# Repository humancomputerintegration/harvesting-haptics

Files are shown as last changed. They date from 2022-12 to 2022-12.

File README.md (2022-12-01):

# source files for "Prolonging VR haptic experiences by harvesting kinetic energy from the user"

For implementation details, please refer to our paper: http://lab.plopes.org/#harvesting-haptics

- schematics: circuits used on PCB.
- code: containing Arduino code for NRF controller, Python code for connecting to NRF controller, and Processing code for intermediate program communicating to any Unity application (VR).
- waterjet: mounting plates and the big gear were cut using a waterjet machine, with 3mm Aluminum. Parts are assembled using M2 and M3 screws, mounted on elbow brace (MOSCARE).
- 3D printing: three gears are 3D printed with PLA.

## additional materials

- NRF52840 Dongle
- harvester (ZSFD-F1HD)
- electro-permanent magnet: Alnico Grade 5 soft magnet + 28 AWG coil
- neodymium magnets
- 8mm bearing
- 5mm ABS shafts

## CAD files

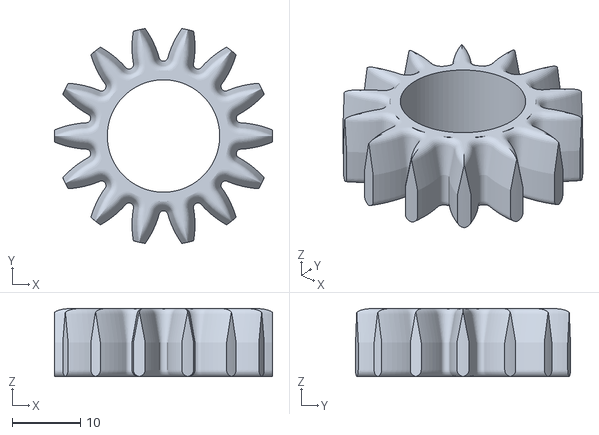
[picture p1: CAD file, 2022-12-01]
3dprinting/gear_clutch.stl
32.0 x 31.5 x 10.0

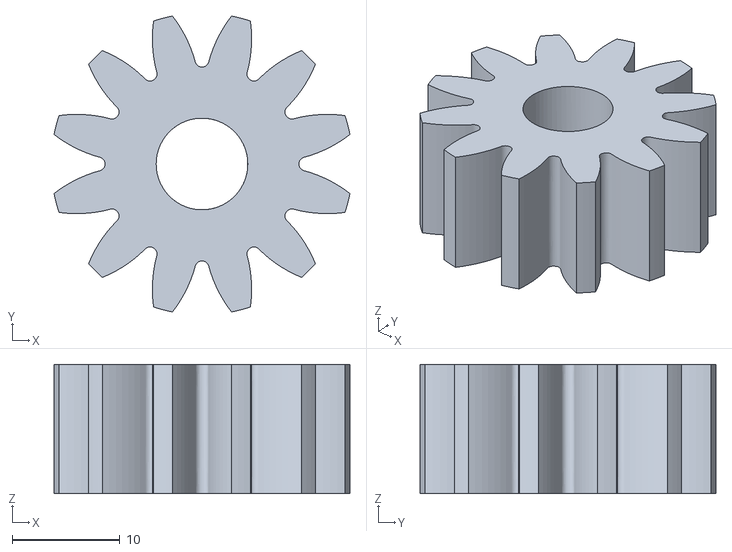
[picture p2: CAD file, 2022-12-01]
3dprinting/gear_middle.stl
27.5 x 27.5 x 12.0

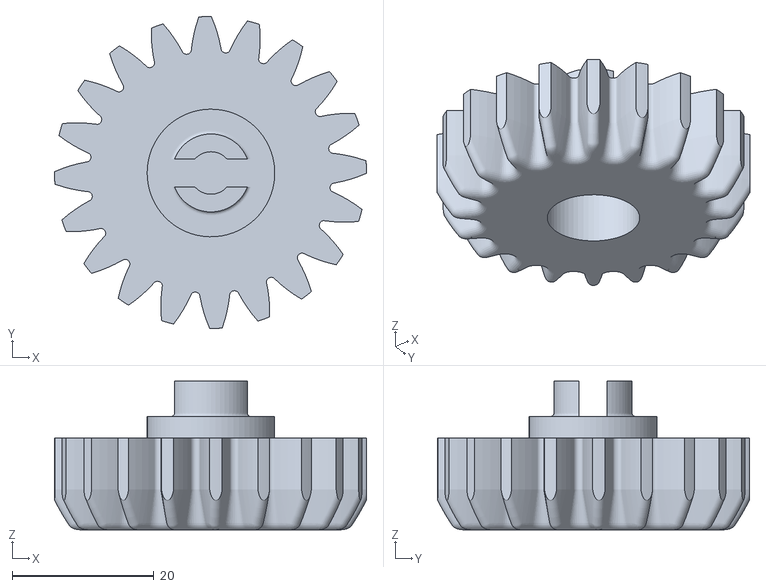
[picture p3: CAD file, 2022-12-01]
3dprinting/gear_harvester.stl
44.0 x 44.0 x 21.0

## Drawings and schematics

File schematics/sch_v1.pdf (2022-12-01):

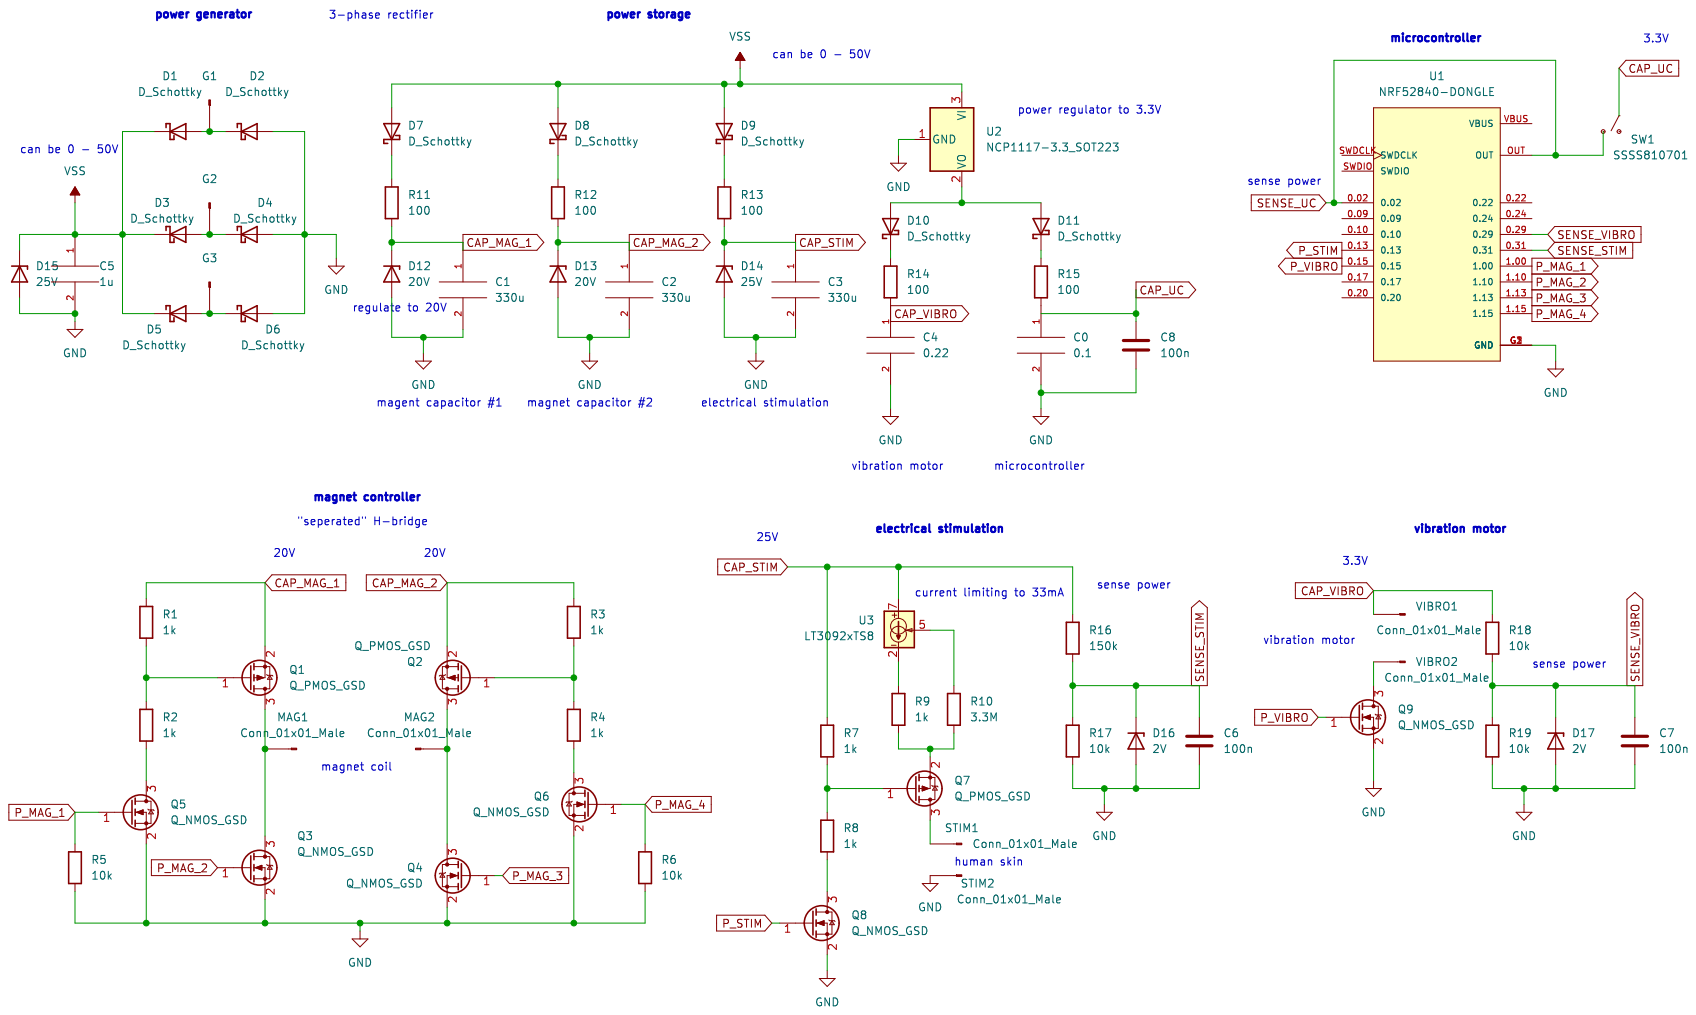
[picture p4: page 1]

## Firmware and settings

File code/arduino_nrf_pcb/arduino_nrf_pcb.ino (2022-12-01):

#include <bluefruit.h>
#include <Adafruit_LittleFS.h>
#include <InternalFileSystem.h>

// BLE Service
BLEUart bleuart; // uart over ble

#define LED_PIN 8
#define SW1_PIN 38

#define BATT_SENSE_PIN 2
#define VIBRO_SENSE_PIN 29
#define EMS_SENSE_PIN 31
#define EPM_1_PIN 32
#define EPM_2_PIN 42
#define EPM_3_PIN 45
#define EPM_4_PIN 47
#define VIBRO_PIN 15
#define EMS_PIN 13

int batt_sense = 0;
int vibro_sense = 0;
int ems_sense = 0;
unsigned long last_time, current_time;


void setup() {
  pinMode(LED_PIN, OUTPUT);
  pinMode(EPM_1_PIN, OUTPUT);
  pinMode(EPM_2_PIN, OUTPUT);
  pinMode(EPM_3_PIN, OUTPUT);
  pinMode(EPM_4_PIN, OUTPUT);
  pinMode(VIBRO_PIN, OUTPUT);
  pinMode(EMS_PIN, OUTPUT);
  pinMode(BATT_SENSE_PIN, INPUT);
  pinMode(VIBRO_SENSE_PIN, INPUT);
  pinMode(EMS_SENSE_PIN, INPUT);
  pinMode(SW1_PIN, INPUT_PULLUP);
  
  digitalWrite(EPM_1_PIN, LOW);
  digitalWrite(EPM_2_PIN, LOW);
  digitalWrite(EPM_3_PIN, LOW);
  digitalWrite(EPM_4_PIN, LOW);
  digitalWrite(VIBRO_PIN, LOW);
  digitalWrite(EMS_PIN, LOW);

  start_ble();
}

void loop() {
  if ( bleuart.available() )
  {
    uint8_t ch;
    ch = (uint8_t) bleuart.read();
    int cmd = ch - '0';

    // turn off everything
    if (cmd == 0) {
      digitalWrite(EPM_1_PIN, LOW);
      digitalWrite(EPM_2_PIN, LOW);
      digitalWrite(EPM_3_PIN, LOW);
      digitalWrite(EPM_4_PIN, LOW);
      // report vibro
      ems_sense = analogRead(EMS_SENSE_PIN);
      bleuart.print(ems_sense);
      bleuart.println();
    }

    // EPM out (unclutch)
    if (cmd == 1) {
      digitalWrite(EPM_1_PIN, HIGH);
      digitalWrite(EPM_3_PIN, HIGH);
      digitalWrite(EPM_2_PIN, LOW);
      digitalWrite(EPM_4_PIN, LOW);
    }
    // EPM in (clutch)
    if (cmd == 2) {
      digitalWrite(EPM_1_PIN, LOW);
      digitalWrite(EPM_3_PIN, LOW);
      digitalWrite(EPM_2_PIN, HIGH);
      digitalWrite(EPM_4_PIN, HIGH);
    }
    // EPM out (unclutch) with timing
    if (cmd == 3) {
      digitalWrite(EPM_1_PIN, HIGH);
      digitalWrite(EPM_3_PIN, HIGH);
      digitalWrite(EPM_2_PIN, LOW);
      digitalWrite(EPM_4_PIN, LOW);
      delay(500);
      digitalWrite(EPM_1_PIN, LOW);
      digitalWrite(EPM_3_PIN, LOW);
      digitalWrite(EPM_2_PIN, LOW);
      digitalWrite(EPM_4_PIN, LOW);
    }
    // EPM in (clutch) with timing
    if (cmd == 4) {
      digitalWrite(EPM_1_PIN, LOW);
      digitalWrite(EPM_3_PIN, LOW);
      digitalWrite(EPM_2_PIN, HIGH);
      digitalWrite(EPM_4_PIN, HIGH);
      delay(500);
      digitalWrite(EPM_1_PIN, LOW);
      digitalWrite(EPM_3_PIN, LOW);
      digitalWrite(EPM_2_PIN, LOW);
      digitalWrite(EPM_4_PIN, LOW);
    }

    // vibration motor short vibration
    if (cmd == 5) {
      tone(VIBRO_PIN, 170);
      delay(300);
      noTone(VIBRO_PIN);
    }
    // long vibration
    if (cmd == 6) {
      tone(VIBRO_PIN, 170);
      delay(900);
      noTone(VIBRO_PIN);
    }

    // EMS
    if (cmd == 7) {
      int repeat = 20;
      for (int i = 0; i<repeat; i++) {
        digitalWrite(EMS_PIN, HIGH);
        delayMicroseconds(200);
        digitalWrite(EMS_PIN, LOW);
        delay(20); //ms
      }
    }

    // long ems
    if (cmd == 8) {
      int repeat = 40;
      for (int i = 0; i<repeat; i++) {
        digitalWrite(EMS_PIN, HIGH);
        delayMicroseconds(200);
        digitalWrite(EMS_PIN, LOW);
        delay(20); //ms
      }
    }
    
    if (cmd == 9) {
      // report battery
      batt_sense = analogRead(BATT_SENSE_PIN);
      bleuart.print(batt_sense);
      bleuart.println();
//      // report vibro
//      vibro_sense = analogRead(VIBRO_SENSE_PIN);
//      bleuart.print(vibro_sense);
//      bleuart.println();
    }
  }

  delay(100); // important to save power
}

void start_ble()
{
  Bluefruit.autoConnLed(false);
  Bluefruit.begin();
  Bluefruit.setTxPower(-16);    // Check bluefruit.h for supported values
  Bluefruit.setName("Harvest");
  //Bluefruit.setName(getMcuUniqueID()); // useful testing with multiple central connections
  Bluefruit.Periph.setConnectCallback(connect_callback);
  Bluefruit.Periph.setDisconnectCallback(disconnect_callback);
  // Configure and Start BLE Uart Service
  bleuart.begin();
  // Set up and start advertising
  startAdv();
}

void startAdv(void)
{
  // Advertising packet
  Bluefruit.Advertising.addFlags(BLE_GAP_ADV_FLAGS_LE_ONLY_GENERAL_DISC_MODE);
  // Bluefruit.Advertising.addTxPower();

  // Include bleuart 128-bit uuid
  Bluefruit.Advertising.addService(bleuart);

  // Secondary Scan Response packet (optional)
  // Since there is no room for 'Name' in Advertising packet
  Bluefruit.ScanResponse.addName();

  /* Start Advertising
     - Enable auto advertising if disconnected
     - Interval:  fast mode = 20 ms, slow mode = 152.5 ms
     - Timeout for fast mode is 30 seconds
     - Start(timeout) with timeout = 0 will advertise forever (until connected)

     For recommended advertising interval
     https://developer.apple.com/library/content/qa/qa1931/_index.html
  */
  Bluefruit.Advertising.restartOnDisconnect(true);
  Bluefruit.Advertising.setInterval(244, 244);    // in unit of 0.625 ms
  Bluefruit.Advertising.setFastTimeout(0);      // number of seconds in fast mode
  Bluefruit.Advertising.start(0);                // 0 = Don't stop advertising after n seconds
}

// callback invoked when central connects
void connect_callback(uint16_t conn_handle)
{
  // Get the reference to current connection
  BLEConnection* connection = Bluefruit.Connection(conn_handle);

  char central_name[32] = { 0 };
  connection->getPeerName(central_name, sizeof(central_name));

  //  Serial.print("Connected to ");
  //  Serial.println(central_name);
}

/**
   Callback invoked when a connection is dropped
   @param conn_handle connection where this event happens
   @param reason is a BLE_HCI_STATUS_CODE which can be found in ble_hci.h
*/
void disconnect_callback(uint16_t conn_handle, uint8_t reason)
{
  (void) conn_handle;
  (void) reason;

  //  Serial.println();
  //  Serial.print("Disconnected, reason = 0x"); Serial.println(reason, HEX);
}

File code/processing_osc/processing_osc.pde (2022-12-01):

import netP5.*;
import oscP5.*;


OscP5 oscP5;

/* a NetAddress contains the ip address and port number of a remote location in the network. */
NetAddress oscPythonBroadcastLocation; 
NetAddress oscUnityBroadcastLocation; 

// OSC sercer address and port
int port_in = 5005;
//String ip_python = "169.254.0.1";
String ip_python = "10.150.30.79";
//String ip_python = "192.168.0.102";
int port_out_python = 5006;
//String ip_unity = "169.254.207.164";
String ip_unity = "10.150.26.114";
//String ip_unity = "192.168.0.1";
int port_out_unity = 5007;

int power = 0;

int timerStart = 0;
int timerInterval = 1000;

int movingAvgSize = 20;
int[] movingArray = new int[20];
int movingArrayIdx = 0;

int emergencyLowPower = 500;
int stableThreshold = 650;
int maxVibroTimes = 10;
int currentVibroTimes = 0;

boolean connected = false;
boolean stable = false;
boolean emergencyStep = false;

PrintWriter log;

void setup() {
  size(400,400);
  frameRate(25);
  
  oscP5 = new OscP5(this, port_in);
  oscPythonBroadcastLocation = new NetAddress(ip_python, port_out_python);
  oscUnityBroadcastLocation = new NetAddress(ip_unity, port_out_unity);
  
  timerStart = millis();
  
  for (int i = 0; i<movingAvgSize; i+=1) {
    movingArray[i] = 0;
  }
  
  log = createWriter("log-"+year()+"-"+month()+"-"+day()+"-"+hour()+"-"+minute()+"-"+second()+".csv"); 
  log.println("hour,minute,second,game_state,device_state");
}


void draw() {
  background(0);
  
  textSize(18);
  fill(255, 255, 255);
  text("python " + ip_python, 10, 30);
  text("unity " + ip_unity, 10, 50);
  
  textSize(28);
  
  if (connected && stable && emergencyStep) {
    text("emergency " + str(power), 10, 120);
  } else if (connected && stable) {
    text("stable " + str(power), 10, 120);
  } else if (connected) {
    text("connected " + str(power), 10, 120);
  } else {
    text("dead", 10, 120);
  }
  
  text("BLE: 0 (off), 1 (in), 2 (out)", 10, 180);
  text("     3 (in timer), 4 (out timer)", 10, 210);
  text("     5 (vib short) 6 (vib long) ", 10, 240);
  text("     7 (ems), 9 (connect)", 10, 270);
  text("VR:  s (stable) d (dying)", 10, 300);
  text("LOG: g (start) e (end)", 10, 330);
  
  // if connected, check power at times
  if (millis() - timerStart > timerInterval) {
    if (connected) {
      sendMessageToBLE(9);
    }
    timerStart = millis();
  }
  
  // estimatation of vibro power
  //if (currentVibroTimes >= maxVibroTimes) {
  //  println("send OSC to Unity: dying because run out of vibro power");
  //  log.println(timestamp()+","+"vibro_cemergency");
  //  log.flush();
  //}
  

  
}

void keyPressed() {
  OscMessage m;
  if (key == CODED) {
    if (keyCode == UP) {
      
    } else if (keyCode == DOWN) {
      
    } else if (keyCode == LEFT) {
      
    } else if (keyCode == RIGHT) {
     
    }
  } else {
    switch(key) {
      case('1'):
        sendMessageToBLE(1);
        log.println(timestamp()+","+"manual_clutch");
        log.flush();
        break;
      case('2'):
        sendMessageToBLE(2);
        log.println(timestamp()+","+"manual_unclutch");
        log.flush();
        break;
      case('3'):
        sendMessageToBLE(3);
        log.println(timestamp()+","+"manual_clutch_timeout");
        log.flush();
        break;
      case('4'):
        sendMessageToBLE(4);
        log.println(timestamp()+","+"manual_unclutch_timeout");
        log.flush();
        break;
      case('5'):
        sendMessageToBLE(5);
        log.println(timestamp()+","+"manual_vibro");
        log.flush();
        break;
      case('6'):
        sendMessageToBLE(6);
        log.println(timestamp()+","+"manual_vibro_long");
        log.flush();
        break;
      case('7'):
        sendMessageToBLE(7);
        log.println(timestamp()+","+"manual_ems");
        log.flush();
        break;
      case('8'):
        sendMessageToBLE(8);
        break;
      case('9'):
        sendMessageToBLE(9);
        break;
      case('0'):
        sendMessageToBLE(0);
        break;
      case(' '):
        sendMessageToBLE(3);
        log.println(timestamp()+","+"manual_unclutch_timeout");
        log.flush();
        break;
      case('a'):
        sendMessageSOSToBLE();
        break;
      case('b'):
        sendMessageVibrosToBLE();
        break;
      case('g'):
        println("log > game start");
        log.println(timestamp()+"game_start");
        log.flush();
        break;
      case('e'):
        println("log > game end");
        log.println(timestamp()+"game_end");
        log.flush();
        break;
      case('s'):
        sendMessageToUnity(1);
        println("send OSC to Unity: stable");
        log.println(timestamp()+","+"manual_stable");
        log.flush();
        break;
      case('d'):
        sendMessageToUnity(2);
        println("send OSC to Unity: dying");
        log.println(timestamp()+","+"manual_emergency");
        log.flush();
        break;
      //case('f'):
      //  sendVRMessage(3);
      //  break;
      //case('g'):
      //  sendVRMessage(4);
      //  break;
    }  
  }
}

void sendMessageToBLE(int n) {
  OscMessage myOscMessage = new OscMessage("/ble");
  myOscMessage.add(n);
  oscP5.send(myOscMessage, oscPythonBroadcastLocation);
}

void sendMessageSOSToBLE() {
  println("send SOS to BLE");
  sendMessageToBLE(5);
  delay(300);
  delay(300);
  sendMessageToBLE(5);
  delay(300);
  delay(300);
  sendMessageToBLE(5);
  delay(300);
  delay(900);
  sendMessageToBLE(6);
  delay(900);
  delay(300);
  sendMessageToBLE(6);
  delay(900);
  delay(300);
  sendMessageToBLE(6);
  delay(900);
  delay(900);
  sendMessageToBLE(5);
  delay(300);
  sendMessageToBLE(5);
  delay(300);
  delay(300);
  sendMessageToBLE(5);
}

void sendMessageVibrosToBLE() {
  println("send sereis of vibro to BLE");
  sendMessageToBLE(8);
  delay(110);
  sendMessageToBLE(8);
  delay(110);
  sendMessageToBLE(8);
}

void sendMessageToUnity(int n) {
  OscMessage myOscMessage = new OscMessage("/vr");
  myOscMessage.add(n);
  oscP5.send(myOscMessage, oscUnityBroadcastLocation);
}
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
